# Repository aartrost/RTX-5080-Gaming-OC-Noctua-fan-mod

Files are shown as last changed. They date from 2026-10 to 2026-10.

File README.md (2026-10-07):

# Fan plate for a deshrouded Gigabyte RTX 5080 Gaming OC

A 3D-printed plate that mounts two Noctua NF-A12x25 (120 mm) fans and one NF-A9 (92 mm) on the bare heatsink
of a Gigabyte RTX 5080 Gaming OC, using four existing holes in the heatsink. The fans screw to the plate from
underneath, with their rubber corner pads removed, and two joiners tie them together on their outer face.

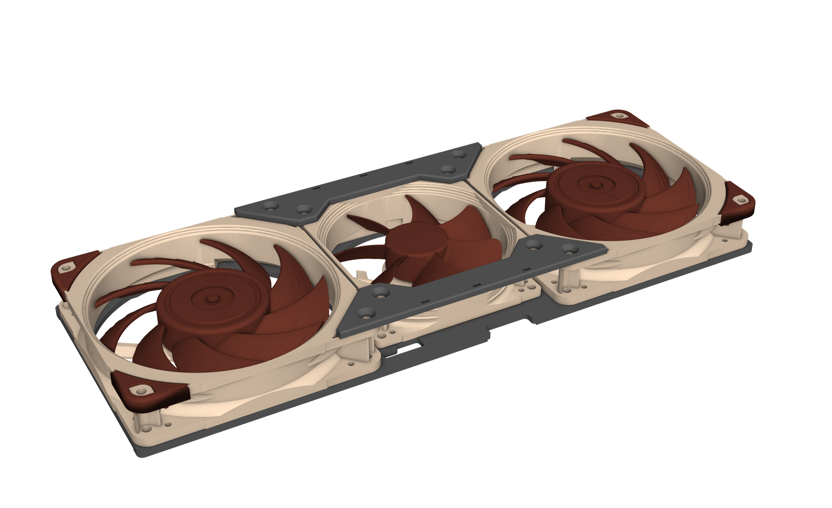
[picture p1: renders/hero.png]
The plate with the three fans and the two joiners, seen from the fan side


Designed around my own card, no guarantees this will fit every other card of the same model. You can
optionally forego the adapter plate and just zip tie the fans to the heatsink.

## Files

| File | What it is |
|---|---|
| `models/5080-gaming-oc-fan-plate_half-A-ports.stl` | Port-side half of the plate |
| `models/5080-gaming-oc-fan-plate_half-B-rear.stl` | Rear half of the plate |
| `models/5080-gaming-oc-fan-plate_full.stl` | The plate in one piece (332.8 x 121.0 mm), for beds that fit it |
| `models/top_joiner.stl` | Joiner for the outer face of the fans. Print two and turn one around |
| `models/5080-gaming-oc-fan-plate_full.step` | The plate as a solid model, for CAD programs |
| `templates/5080-plate-hole-template_*.pdf` | 1:1 paper templates of the hole layout (US Letter in two pages, US Legal in one) |

## Printing

- **The files are true size. Scale them for shrinkage.** Print one half at 100%, measure the plate width
  (modelled at 121.0 mm), and scale X and Y by 121.0 divided by your measurement. The parts
  shown here were printed in ABS at 100.7%, Z at 100%. Over the 310.75 mm between the rail screw holes,
  even 0.5% is 1.5 mm, so do not skip this.
- Use a material that tolerates heat. ABS, ASA or PETG; not PLA.

## Hardware

- 4 M2 screws with a 3.75 mm cylindrical head, 6 mm or longer, and 4 M2 nuts.
- 12 standard case-fan screws for the plate, plus 8 for the two joiners.

## Assembly

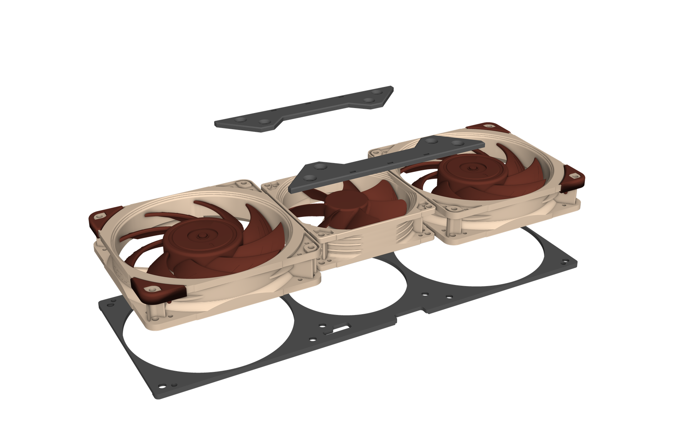
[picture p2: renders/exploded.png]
Exploded view: plate, fans and joiners


1. Push the two halves together until the flat faces touch.
2. Fit the four M2 screws into their pockets from the fan side. The pockets are made slightly too tight on
   purpose: push each screw in with the tip of a soldering iron, like a heat-set insert, and the plastic
   closes around the head so the screw is held firmly and cannot spin.
3. Screw the fans to the plate from the underside.
4. Pass the fan connectors through the stepped openings beside the 92 mm fan and slide each wire into the
   shallow end of its opening. Do this before the plate goes on the card.

   <p>
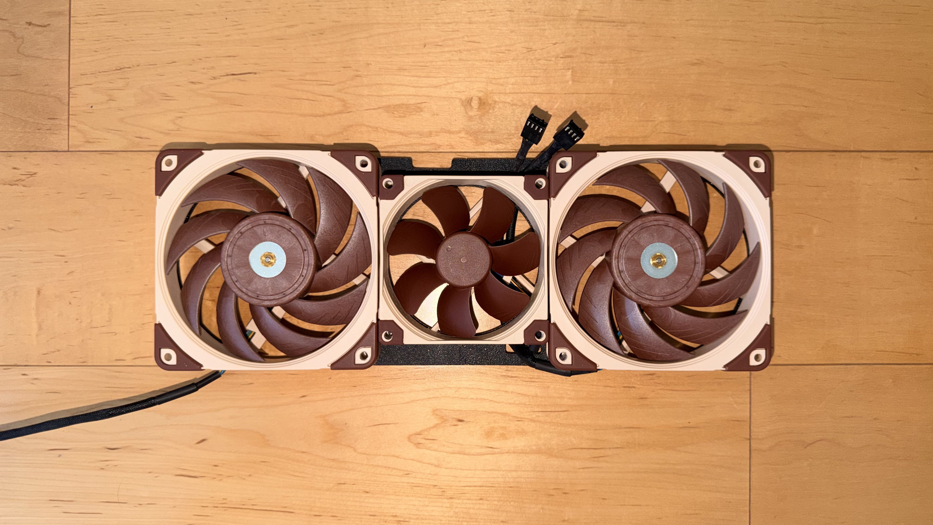
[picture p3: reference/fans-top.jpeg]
Fans and joiners on the plate, seen from the intake side
   
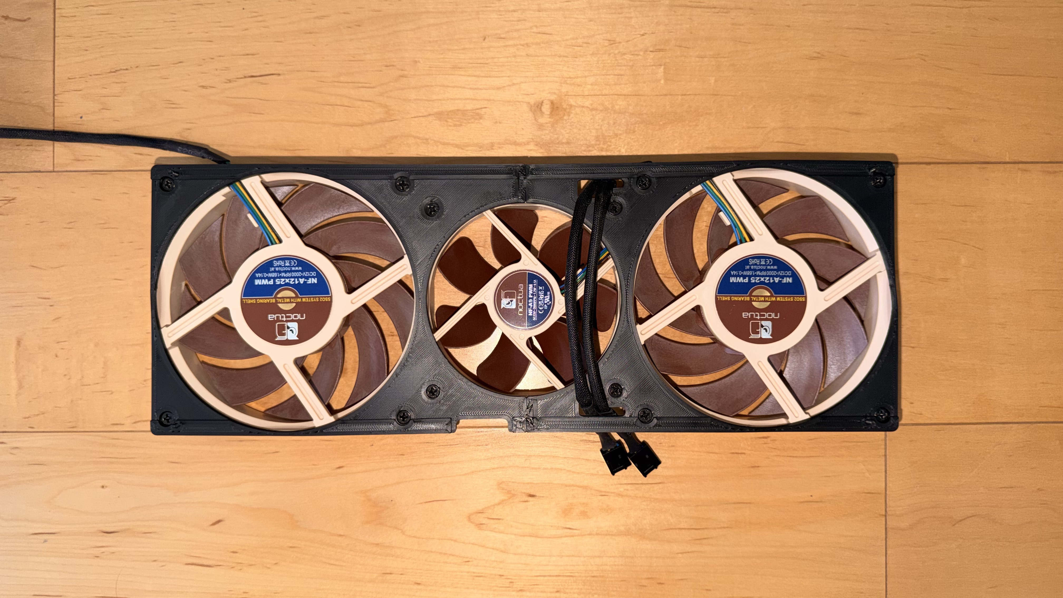
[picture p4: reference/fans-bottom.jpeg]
The same assembly from the heatsink side, wires routed through the openings
   
   </p>

5. Lower the plate onto the heatsink so the ridges rest on the bars and the M2 screws pass through the bar
   holes, then fit the nuts from below.
6. Screw a joiner across the outer face of the fans on each long side.

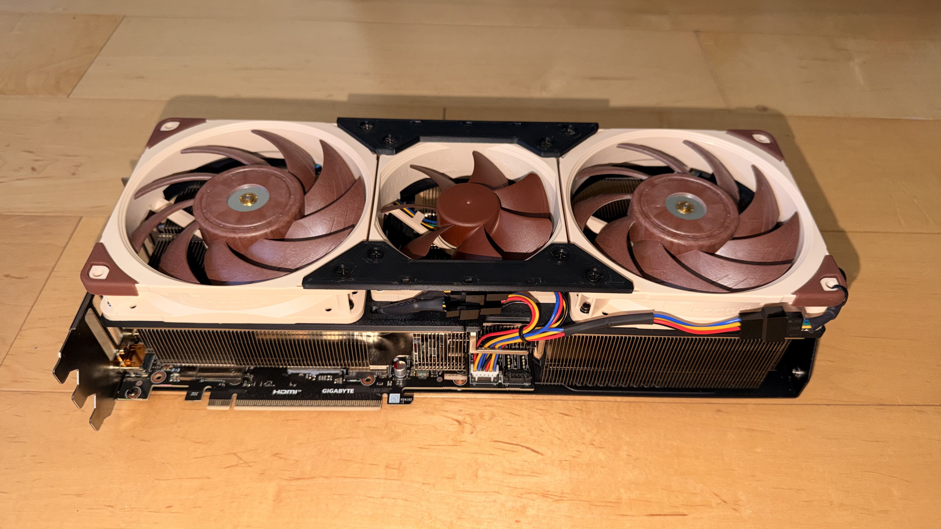
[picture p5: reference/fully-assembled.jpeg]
The finished assembly on the card


## Fan harness

The card has a single fan header, a 2.0 mm pitch JST PHD 2 x 6 connector, so the three fans need a custom
harness. This is the pinout of the harness's own connector, the female JST plug that goes onto the card's header:

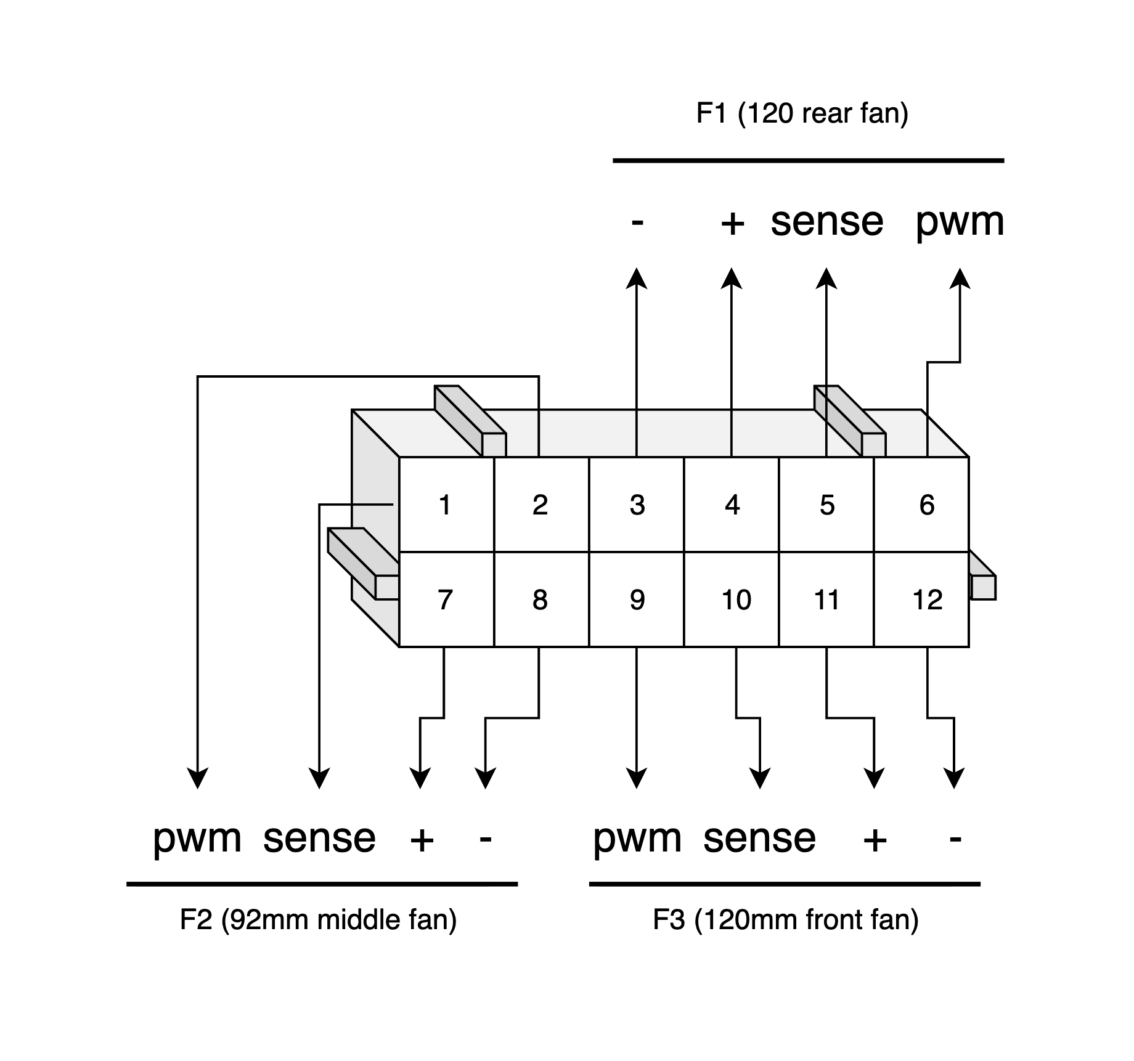
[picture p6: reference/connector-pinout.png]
Pinout of the harness connector


The harness in the pictures was made from two kits: [4-pin fan connector plugs](https://www.amazon.com/dp/B08HYTGH7D)
for the fan side and a [JST PHD connector kit](https://www.amazon.com/dp/B0CKZF94RR) for the card side. You need
a crimp tool to attach the JST connector wires to the fan header pins.

Before printing, lay the paper template on the heatsink at 100% and check that the four ringed crosses sit
over the bar holes. The plate extends 5.9 mm past the port end of the heatsink and 7.9 mm
past the rear; make sure your card and case have that room.

## Changing the design

Everything is generated by a Python script. Parameters, what they do, and how to regenerate the files are in
[docs/changing-the-design.md](docs/changing-the-design.md).

## License

Models, templates and documentation: [CC BY 4.0](LICENSE-CC-BY-4.0). Scripts: [MIT](LICENSE). Noctua's fan
CAD files in `reference/` are Noctua's, included as downloaded from their website.

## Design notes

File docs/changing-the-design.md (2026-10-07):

# Changing the design

The plate, the joiner, this file and the README are all written by `fan_plate.py`. Change a number at the top
of the script, run it, and every file follows. All dimensions are in millimetres. The view is from the fan
side with the ports on the left: X runs along the card, Y across it, Z = 0 is the fin tops.

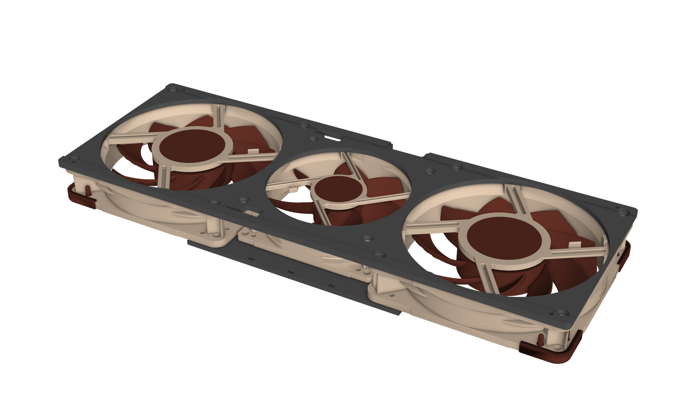
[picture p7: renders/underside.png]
The underside of the plate, which faces the heatsink


## Setting up

You need Python 3.10 to 3.12 with CadQuery. The paper templates need `reportlab` and the renders `pyvista`.
Install into a virtual environment:

    python3 -m venv .venv
    .venv/bin/pip install -r requirements.txt

## Regenerating

    .venv/bin/python fan_plate.py              # models/ (STL, STEP, joiner), README.md, this file, preview/*.svg
    .venv/bin/python joiner.py                 # the joiner on its own
    .venv/bin/python tools/paper_template.py   # templates/*.pdf (its numbers are typed in by hand: update them
                                               # whenever holes, fans, cutout or openings move)
    .venv/bin/python tools/render_meshes.py    # fine meshes of the fans, plate and joiner for rendering, into preview/render/
    .venv/bin/python tools/render.py           # renders/: the pictures

The fan screws and the rail screws sit very close together at the corners. After any change to the holes or
the fans, read the lines the script prints for each rail hole: they give the plastic left between the screw
pocket and the nearest fan screw hole. Keep that above about 1 mm.

## Shrinkage, in more detail

Rough shrinkage by material. Treat these as starting points, since brand, chamber temperature and part
position on the bed all change the result:

| Material | Typical shrinkage |
|---|---|
| PLA | 0.2% to 0.5% (softens near a hot GPU, so not recommended) |
| PETG | 0.3% to 0.6% |
| ABS, ASA | 0.4% to 0.8% (the original prints measured 0.5% to 0.7%; the final print used 100.7%) |
| Polycarbonate | 0.5% to 0.8% |
| Nylon | 1% to 2%, less for fibre-filled grades |

Shrinkage can differ along and across a long part. To check, also measure the port-side half from its outer
end to the flat face where the halves meet (modelled at 165.4 mm) and use a separate factor for that axis.
Measure on a single half, never across the joint. Print the final parts with the same material, settings and
bed position as the test.

## Parameters

**Different rail screws**

- `HEAD_D`: diameter of the head pocket. Use the head diameter plus about 0.05 for a snug fit.
- `HEAD_DEPTH`: depth of the pocket. Use the head height plus about 0.2.
- `RAIL_HOLE_D`: clearance hole for the thread.
- `PLATE_T`: keep it at least 0.8 more than `HEAD_DEPTH`, so there is a floor under the head.

**Different fan screws**

- `FS_HEAD_D`, `FS_TAPER_H`, `FS_THREAD_D`: head diameter, height of the tapered part of the head, and thread diameter.
- `FS_RECESS`: how far the head sits below the underside of the plate.

**Different hole positions on the heatsink**

- `RAIL_CC_Y`: distance between the two rows of holes, across the card.
- `TOP_BAR`, `BOT_BAR`: length of each bar. Both bars are assumed to end flush at the rear of the heatsink.
- `TOP_INSET`, `BOT_INSET`: distance from the end of each bar to the centre of its hole.
- `RAIL_STRETCH`: a correction added to the lengthwise spacing, split between both ends.
- `FIN_L`, `FIN_W`: length and width of the heatsink.
- `PAD_H`: height of the ridges. Set it to how far the bars sit below the fin tops, or slightly more.

**Fan positions**

- `FAN_SHIFT`: where the fan row starts, measured from the port end of the heatsink (negative is in front of it).
- `FAN_GAP`: gap between neighbouring fans.
- `FAN_OFF_Y`: sideways offset of the whole fan row.
- `F120`, `F92`, `F92_FRAME_HALF`: fan sizes, screw spacing and opening diameters, for fans other than these Noctuas.
  The joiner (`joiner.py`) takes its hole positions from the same layout.

**Wire openings and cutout**

- `FIN_GAP_START`, `FIN_GAP_W`: position and width of the gap in the fins that the wire openings sit over.
- `RAIL_W`: width of the bar there. The openings start at its inner edge.
- `CONN_W`, `WIRE_SLOT_H`: width of the connector part and depth of the wire slot.
- `WIRE_START`, `WIRE_END`, `WIRE_DEPTH`: the cutout in the bottom edge, measured from the two bottom rail holes.

**Splitting for the print bed**

- `SPLIT_X`: where the halves join. Keep it inside the 92 mm opening and clear of the edge cutout.
- `JOINT_CLEAR`, `TAB_NECK`, `TAB_LEN`: fit and size of the dovetails.

The paper templates are drawn for this exact design and are not regenerated by the script, so after changing
hole positions, check the new layout another way, for example by printing a thin test piece of each corner.

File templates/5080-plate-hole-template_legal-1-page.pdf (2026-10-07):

# Hole template, full length (view from the fan side; ports to the left, rear to the right)

Rail holes: 310.75 mm apart on the top bar, 307.25 mm on the bottom bar, 112.25 mm across.

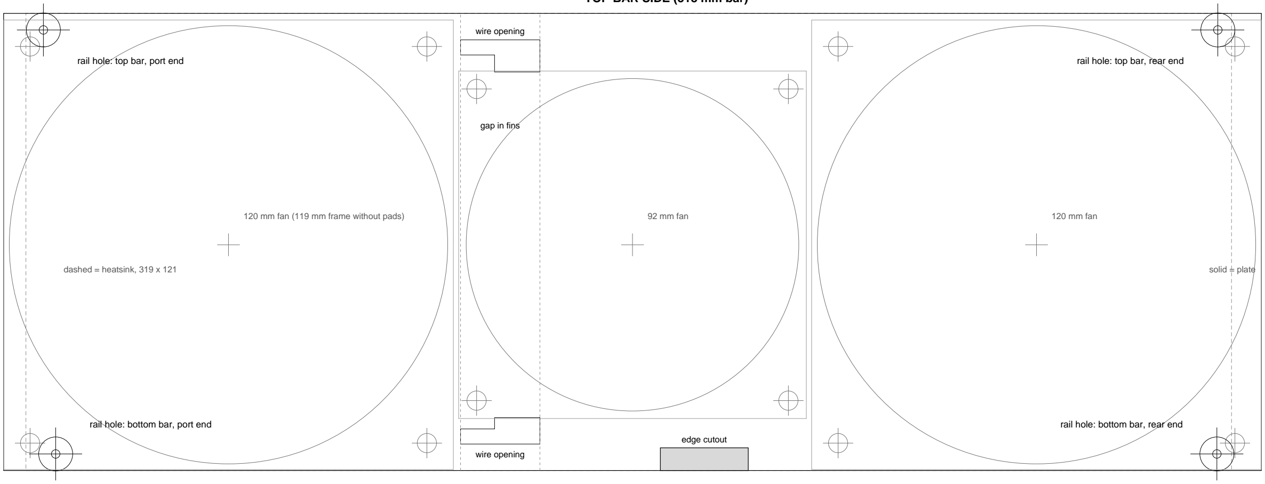
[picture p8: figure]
edge cutout; gap in fins; wire opening

Scale check: this ruler must measure exactly 100 mm. Print at 100% / "Actual size", not "Fit to page".

## TOP BAR SIDE (318 mm bar)

## BOTTOM BAR SIDE (315 mm bar, PCIe connector side)

rail hole: top bar, port end | rail hole: top bar, rear end
rail hole: bottom bar, port end | rail hole: bottom bar, rear end
120 mm fan (119 mm frame without pads) | 92 mm fan | 120 mm fan
dashed = heatsink, 319 x 121 | solid = plate

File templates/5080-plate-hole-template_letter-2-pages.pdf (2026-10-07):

# Hole template, page 1 of 2: PORT END (view from the fan side; ports to the left)

Cut page 2 along its dashed join line, lay it over this page so the join lines and both ringed crosses line up, then tape.

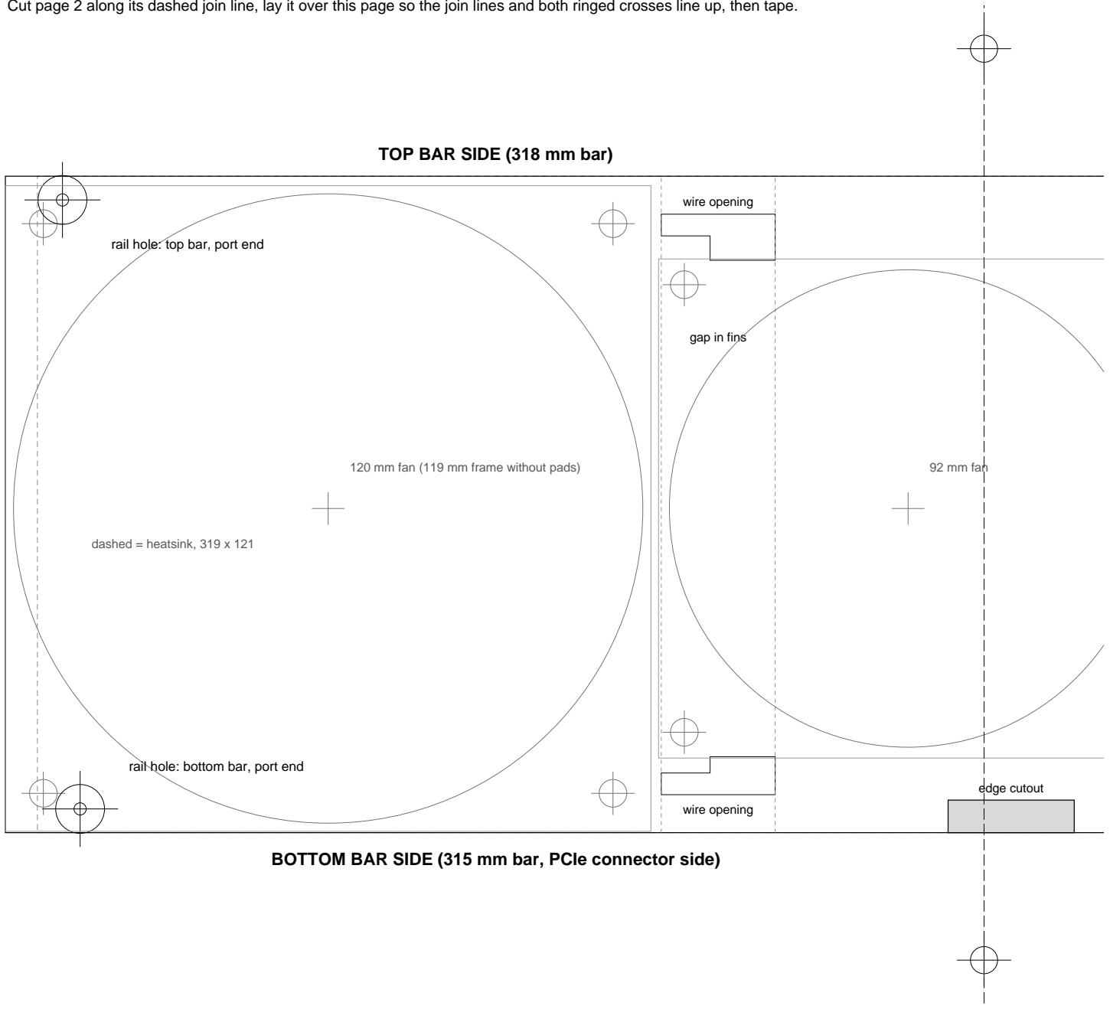
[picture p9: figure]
edge cutout; gap in fins; wire opening; TOP BAR SIDE (318 mm bar); rail hole: top bar, port end; rail hole: bottom bar, port end; dashed = heatsink, 319 x 121

Scale check: this ruler must measure exactly 100 mm. Print at 100% / "Actual size", not "Fit to page".

## BOTTOM BAR SIDE (315 mm bar, PCIe connector side)

120 mm fan (119 mm frame without pads) | 92 mm fan

# Hole template, page 2 of 2: REAR END (view from the fan side; rear to the right)

Cut along the dashed join line on the left, then overlay on page 1 matching the two ringed crosses.

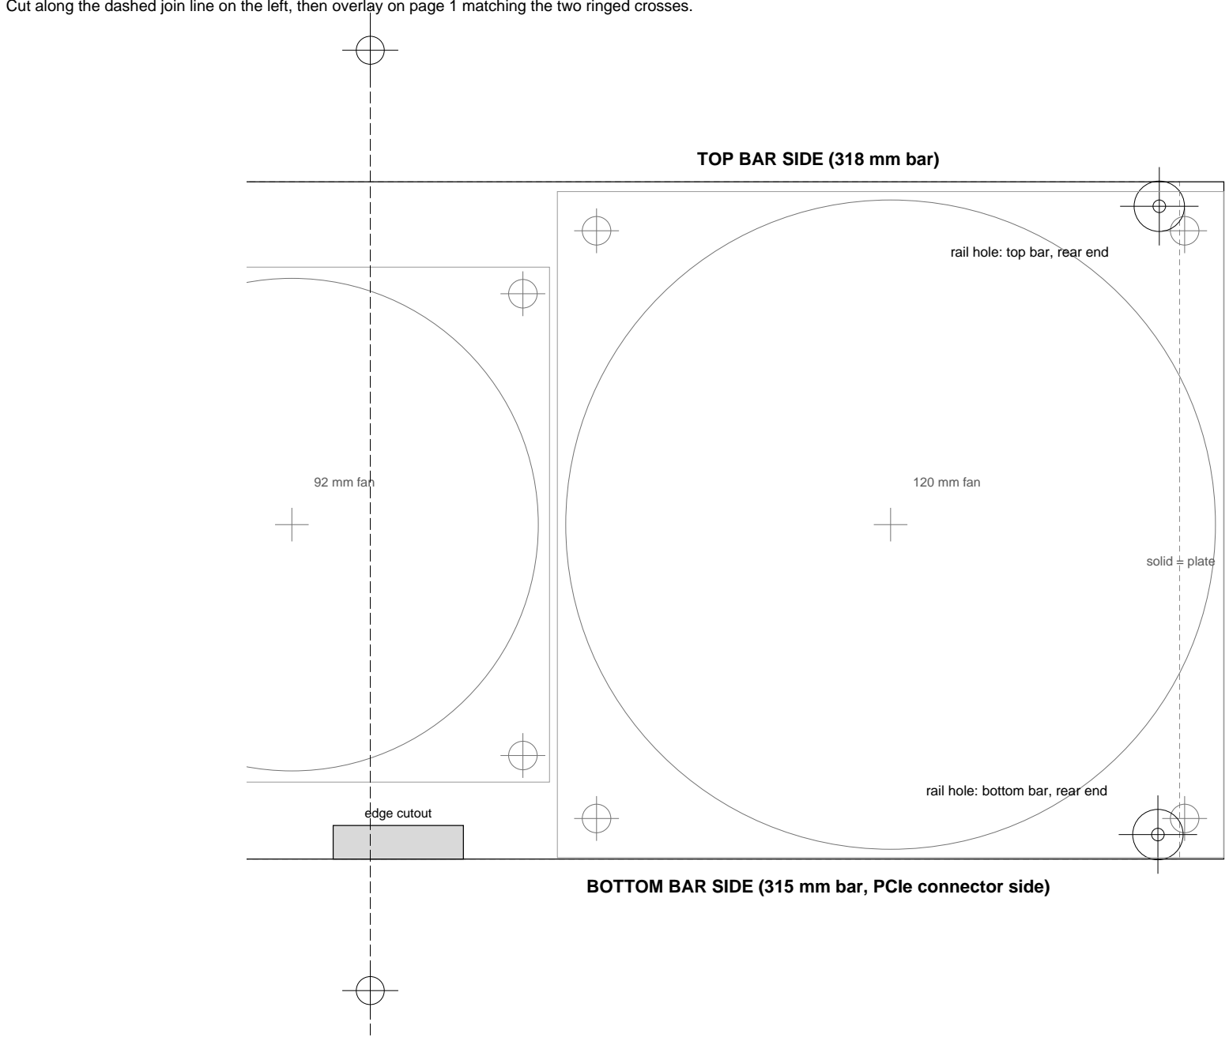
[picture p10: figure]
edge cutout; gap in fins; wire opening; TOP BAR SIDE (318 mm bar); rail hole: top bar, rear end; rail hole: bottom bar, rear end; solid = plate

Scale check: this ruler must measure exactly 100 mm. Print at 100% / "Actual size", not "Fit to page".

## BOTTOM BAR SIDE (315 mm bar, PCIe connector side)

120 mm fan (119 mm frame without pads) | 92 mm fan | 120 mm fan

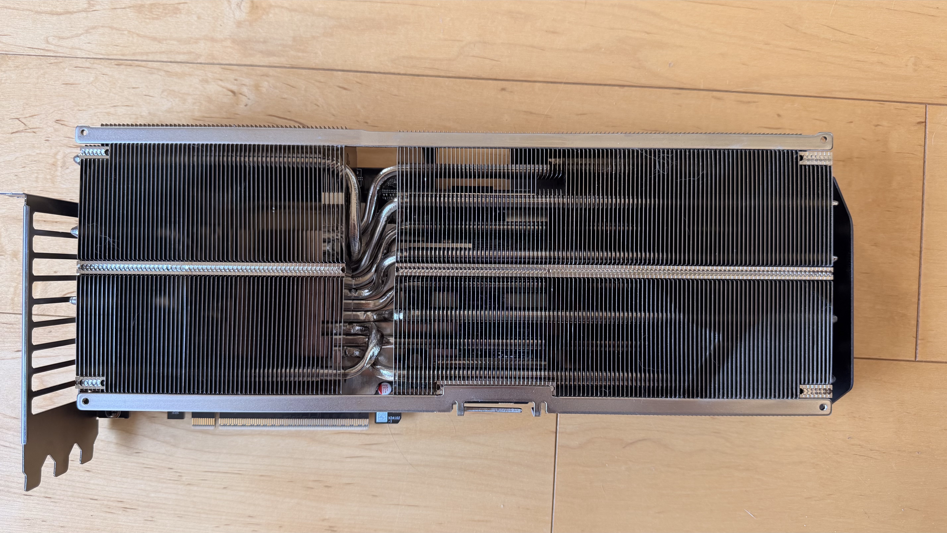
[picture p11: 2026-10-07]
reference/heatsink-bare.jpeg

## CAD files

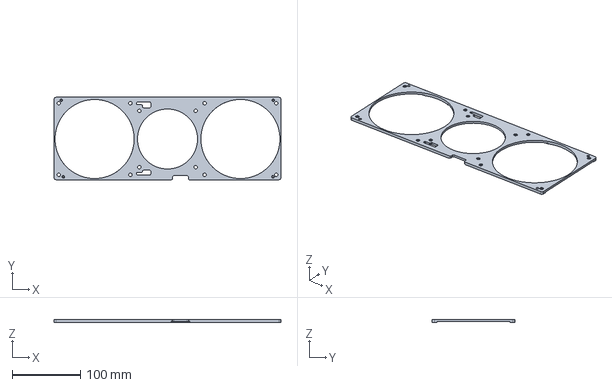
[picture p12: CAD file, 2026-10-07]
models/5080-gaming-oc-fan-plate_full.step
332.8 x 121.0 x 4.00 mm

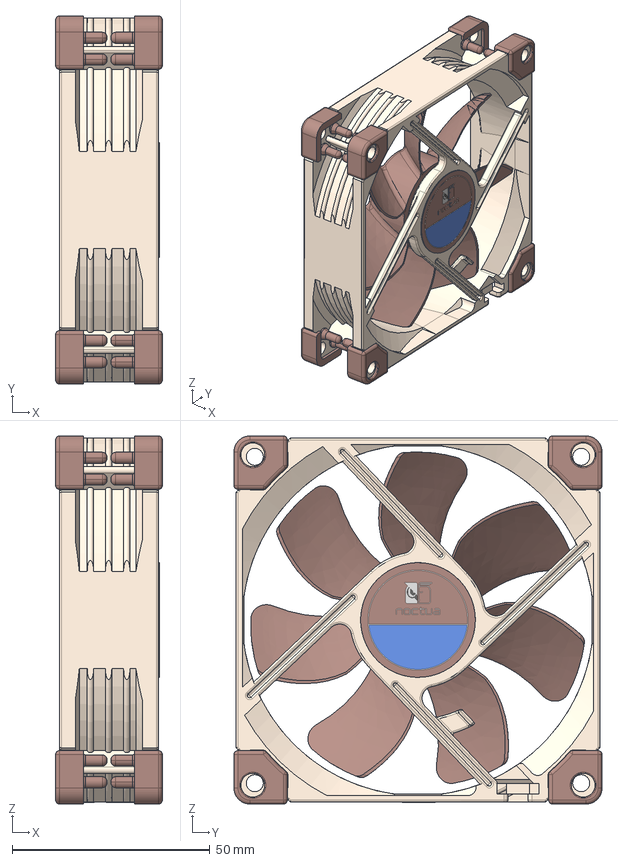
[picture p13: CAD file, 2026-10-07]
reference/NF-A9_Public-Cad.stp
27.0 x 93.0 x 93.0 mm
A9_Frame-public
A9_Impeller-public
NA-AVP5 x 8
Fan-Label-D29mm-Regular

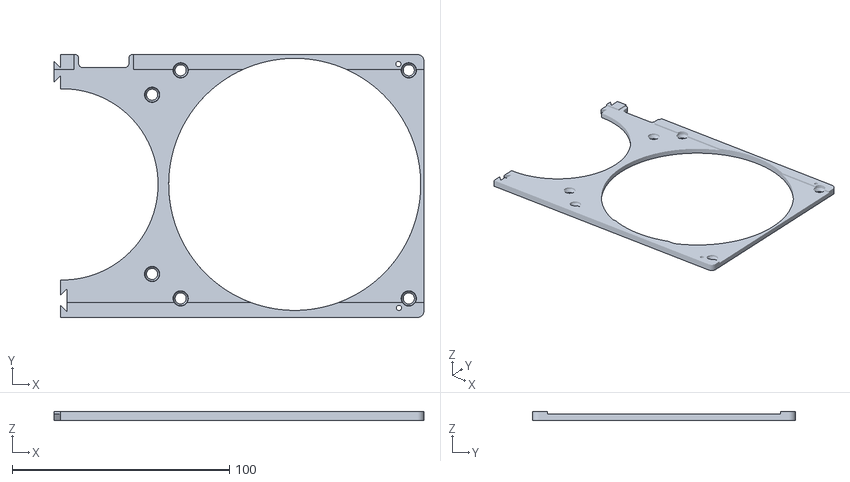
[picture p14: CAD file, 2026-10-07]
models/5080-gaming-oc-fan-plate_half-B-rear.stl
170.3 x 121.0 x 4.00

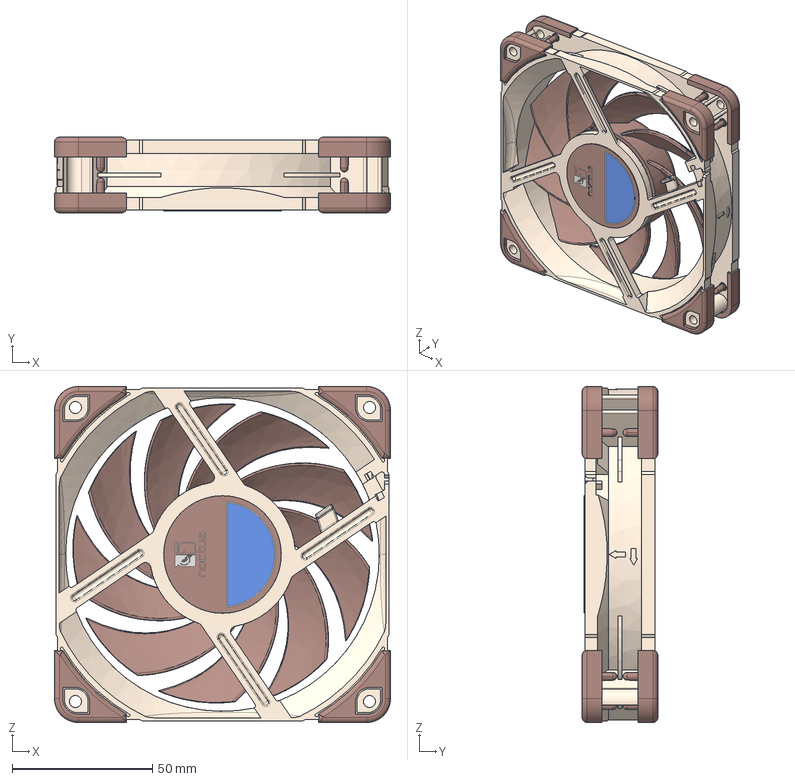
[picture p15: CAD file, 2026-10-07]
reference/NF-A12x25_Public-CAD.stp
120.0 x 27.0 x 120.0 mm
NF-A12x25_Frame-Public
NF-A12x25_Impeller-Public
NA-AVP1 x 8
Fan-Label-D42mm

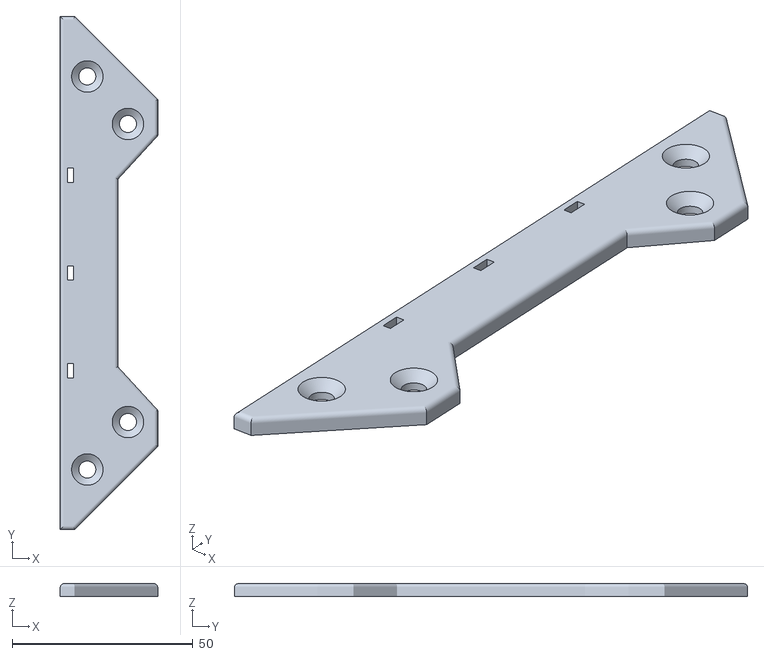
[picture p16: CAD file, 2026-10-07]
models/top_joiner.stl
27.0 x 142.0 x 3.50

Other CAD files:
models/5080-gaming-oc-fan-plate_half-A-ports.stl
models/5080-gaming-oc-fan-plate_full.stl
